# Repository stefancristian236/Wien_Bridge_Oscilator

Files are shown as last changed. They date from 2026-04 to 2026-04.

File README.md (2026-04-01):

# Wien Bridge Oscillator

## Schematic & PCB
Full schematic and simulation is available in the 'Wien_oscillator' file in LTSpice.
The PCB can be accessed using a proper PCB design software and accessing the 'oscilatorWien3.brd' file.
The circuit was simulated in LTSpice and routed in OrCAD.

## Documentation
Full project documentation (schematic, simulation results, design decisions) is available in 'DOC.pdf'.

## Gerber Files
Fabrication-ready files are in the `/Layout` folder.

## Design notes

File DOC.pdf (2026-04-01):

Anul universitar: 2025-2026

## UNIVESITATEA NAȚIONALĂ DE ȘTIINȚE ȘI TEHNOLOGIE POLITEHNICĂ BUCUREȘTI

FACULTATEA DE ELECTRONICĂ, TELECOMUNICAȚII ȘI

TEHNOLOGIA INFORMAȚIEI

## PROIECT 1 – CIRCUITE ELECTRONICE FUNDAMENTALE 2

## OSCILATOR CU PUNTE WIEN

Profesori Îndrumători:

S.I. Dr.Ing. Miron Cristea Dr.Ing. Niculina Draghici

Student:
Grecu Stefan-Cristian
Grupa 434C

## Cuprins

## 1. Tema Proiectului(N = 16)

### Se dorește proiectarea unui oscilator cu punte Wien având următoarele specificații:

- Frecvența de oscilație fixă, f = N [kHz] - Amplitudinea semnalului de la ieșire peak-to-peak de N/3 + 2 [V] - Sarcina la ieșire de 50N [Ω] - Rețeaua de reactive pozitivă din componenta oscilatorului să fie de tip Wien - Domeniul temperaturilor de funcționare 0 – 70 grade Celsius - Amplificarea în tensiune minimă a amplificatorului să fie minim 200 - Se folosesc componente discrete, fără circuite integrate

### Pentru N = 16, obținem următoarele specificații:

### - f = 16 [kHz] - App = 7.33 [V] - Sarcina R = 800 [Ω]

## 2. Schema Bloc

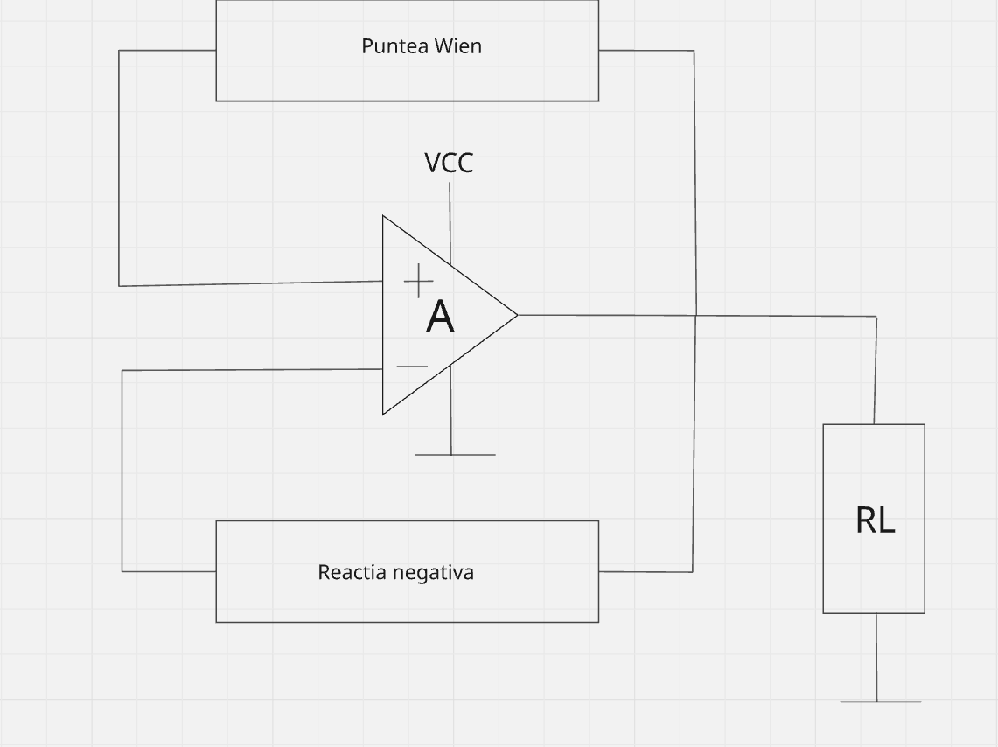
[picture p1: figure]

## 2.1 Blocul “Puntea Wien”

Reprezintă reacția pozitivă a amplificatorului operațional notat cu A. Acesta asigură, prin intermediul unei legături dublu π (deoarece există o legătură RC serie cu o legătură RC paralel), frecvența de oscilație de la ieșire. Reacția este fizic implementată cu ajutorul a 3 rezistențe și 2 condensatoare care, după formulaf0 =

1
2πRC

trebuie să rezulte N,

adică valoarea de 16 [kHz].

## 2.2 Blocul “Reactia Negativă”

Rolul principal al acestui bloc este de a modifica câștigul amplificatorului, astfel încât în buclă deschisă să fie cât mai mare, iar în buclă închisă acesta să fie exact 3 pentru a putea susține oscilațiile. Totodată, acest bloc se ocupă cu modificarea amplitudinii semnalului.

## 2.3 Blocul amplificator(A)

Acest bloc este inima circuitului; rolul acestuia este de a amplifica diferența de potențial de la intrările sale. În cazul lui, acesta trebuie să aibă o amplificare cât mai mare (de dorit, sau teoretic, această amplificare trebuie să fie chiar infinită).

## 2.4 Blocul RL(sarcina)

Acesta are rolul de consumator în circuitul nostru; astfel, acesta este conectat la ieșirea opamp-ului și pe el pică semnalul generat de circuit.

## 3.Implementarea Blocurilor

Ulterior, după ce am implementat în LTSpice schema bloc din capitolul anterior, am ajuns la circuitul funcțional de mai jos, urmând ca în cele ce urmează să trecem prin fiecare bloc în parte.

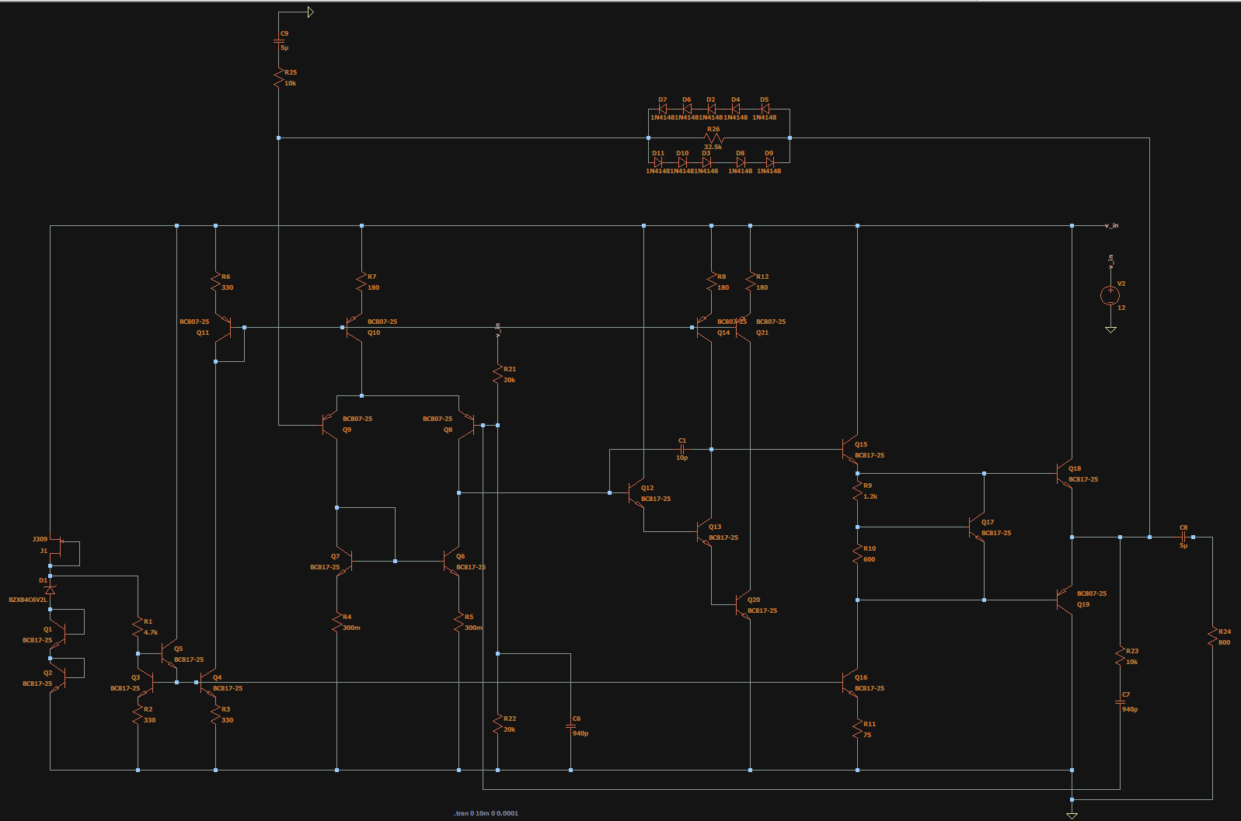
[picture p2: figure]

## 3.1 Blocul “Puntea Wien”

Așa cum am specificat în capitolul anterior, rolul punții Wien este de a genera oscilații, fiind formată dintr-o rețea RC serie și o rețea RC paralel, numită și „dublu π”.

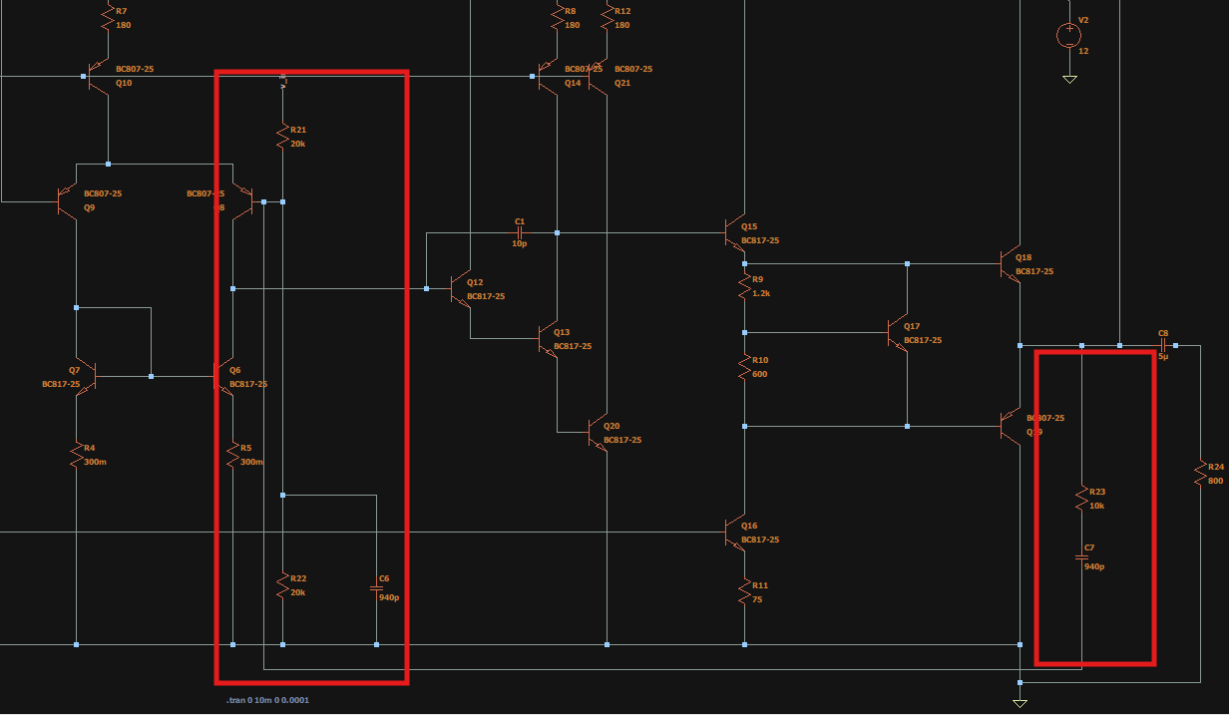
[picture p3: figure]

Rețeaua este construită din 2 rezistențe R21 și R22 de 20k legate în paralel, astfel rezistența echivalentă a acestora va fi 10k. În cazul condensatoarelor am utilizat capacitate de 940 [pF]; chiar dacă în urma calculelor ajungem la o frecvență mai mare de 16k, în practică, din cauza că circuitul introduce o formă de phase lag, frecvența este apropiată de 16 [kHz]. În cele ce urmează efectuăm calculul pentru frecvența necesară.Frecvența se calculează cu formula:f0 =

1
2πRC

Știm că f0 = 16[Kℎz] => RC =

1
2πf0

=> RC =

1
2π⋅16

și dacă rezolvăm pentru una din

componente : R =

1
2π⋅16C

, și pentru valoarea C = 900[pF] obținem o rezistență

R ≈ 11[kΩ] dar din cauza fenomenului de phase lag am ales valorile

R = 10[kΩ] si C = 940[pF], care ne oferă o valoare apropiată de frecvența țintă, 16 [kHz].

## 3.2 Blocul „Reacție Negativă”

Reacția negativă are loc pentru a modifica câștigul amplificării, să menținem amplificarea la valoarea de 3, în cazul nostru, inclusiv să compensăm scăderea acesteia cu ajutorul unor perechi de diode în antiparalel și, nu în ultimul rând, să obținem amplitudinea țintă.

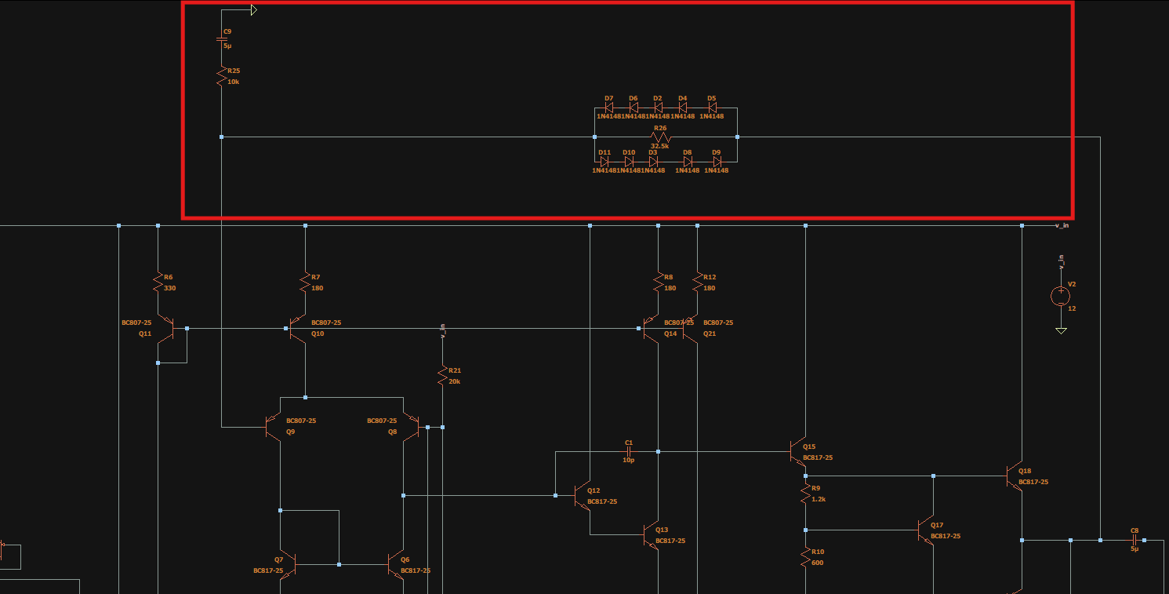
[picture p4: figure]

Reacția negativă este formată din rezistențele R26, R25, condensatorul C9 și cele 10 diode, menite să mențină amplificarea stabilă (sau, mai corect, să o compenseze) și să întrețină oscilațiile.
În cazul unui oscillator cu punte Wien, amplificarea în buclă închisă trebuie să fie exact 3; ținând cont că avem un amplificator neinversor, putem scrie că

vout = (1 +

Rf
Ri) Vin ⇒

vout

vin

= 1 +

Rf
Ri

⇒ A = 1 +

R26
R25

, cum A = 3 ⇒

R26
R25

= 2, deci obținem

condiția de oscilație: R26 = 2R25, dar acest lucru este teoretic, deoarece în practică amplificatorul ar avea nevoie de mai mult pentru a începe oscilațiile, motiv pentru care în cazul nostru R26este de aproximativ 3 ori R25.
Diodele au rolul de a ajuta la menținerea amplitudinii oscilațiilor, dar și pentru compensarea amplificării; astfel se asigură amplitudinea și oscilațiile necesare.

## 3.3 Blocul Amplificator (A)

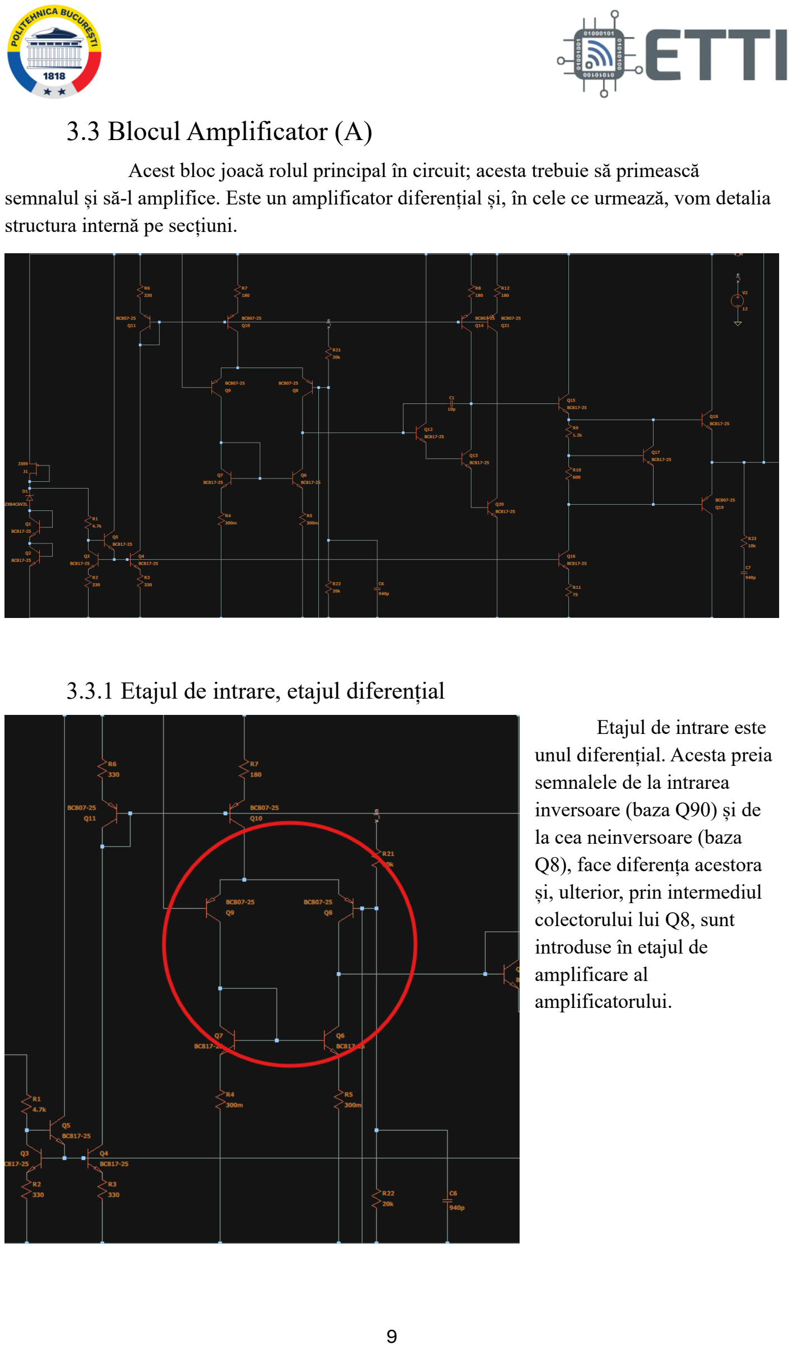
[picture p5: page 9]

Acest bloc joacă rolul principal în circuit; acesta trebuie să primească semnalul și să-l amplifice. Este un amplificator diferențial și, în cele ce urmează, vom detalia structura internă pe secțiuni.

### 3.3.1 Etajul de intrare, etajul diferențial

Etajul de intrare este
unul diferențial. Acesta preia semnalele de la intrarea
inversoare (baza Q90) și de la cea neinversoare (baza
Q8), face diferența acestora și, ulterior, prin intermediul colectorului lui Q8, sunt
introduse în etajul de
amplificare al
amplificatorului.

### 3.3.2 Etajul de amplificare

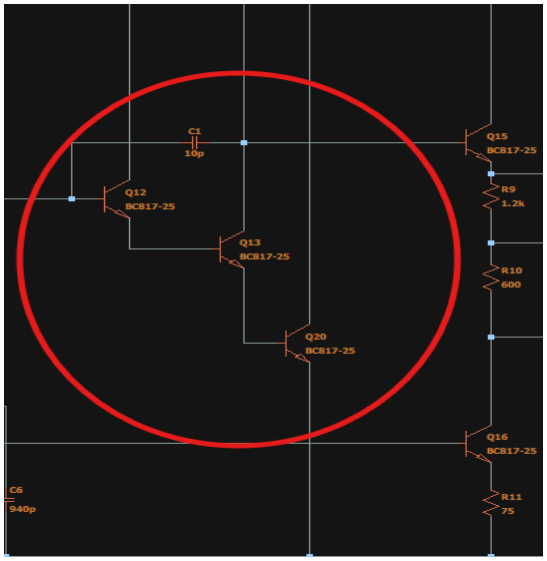
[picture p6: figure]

Etajul de amplificare este confecționat din 3 tranzistoare bipolare montate în cascadă și un condensator de compensare Miller.

Condensatorul are un rol important în menținerea stabilității circuitului. Totodată, acesta profită de efectul Miller, Cechivalent = C(1+Av

), unde Aveste câștigul etajului care se află în conexiune Darlington. Prin acest efect, condensatorul, văzut dinspre bază, are o capacitate mai mare, factor important pentru filtrarea semnalului și care ajută la menținerea unor oscilații stabile.

### 3.3.3 Etajul de ieșire

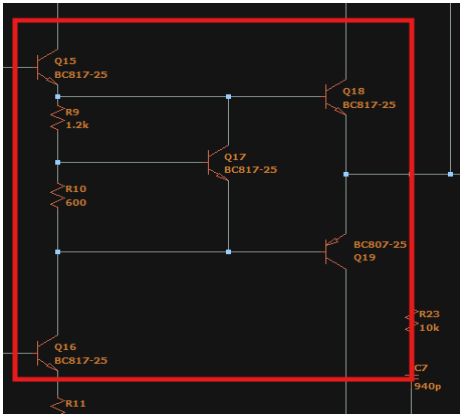
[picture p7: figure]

Ieșirea amplificatorului este de clasă AB. Tranzistorul Q17 are rolul de a menține un curent de repaus în bazele tranzistorilor Q18 și Q19, motiv pentru care ei rămân ușor sau aproape deschiși chiar și dacă nu ajunge semnal la ei. Aceasta asigură eliminarea distorsiunilor și o ieșire mai liniară.

### 3.3.4 Sursa de current si oglinzile de current

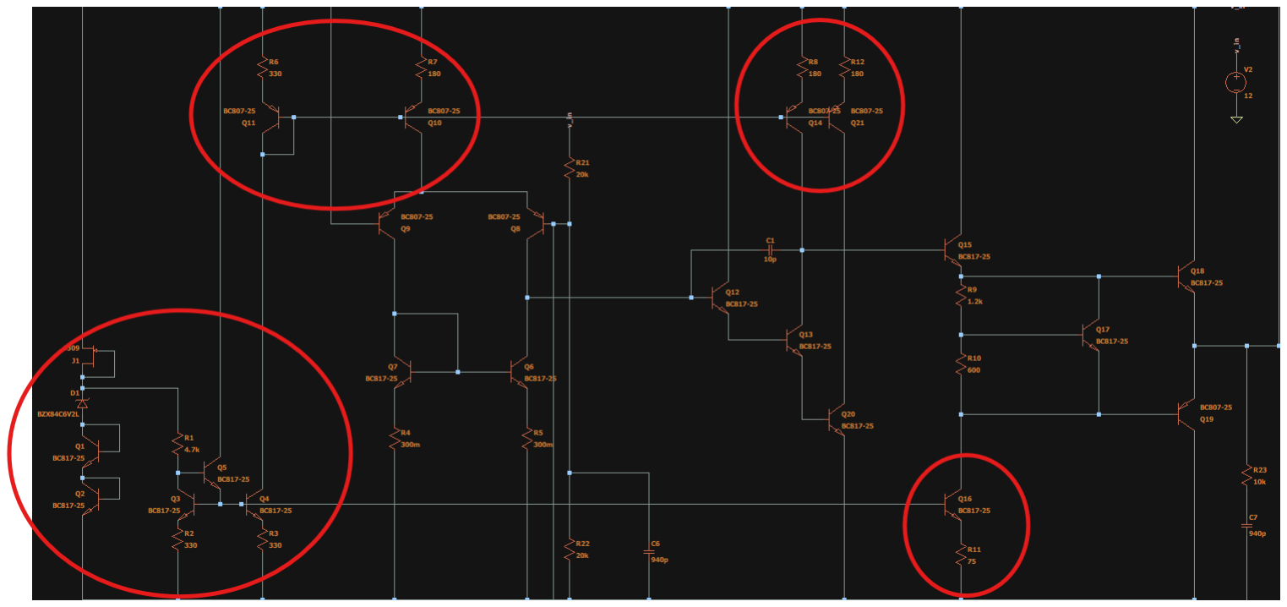
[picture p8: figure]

Sursa de curent asigură polarizarea corectă a tranzistoarelor; utilizarea unei surse oferă un curent constant, lucru care nu ar fi fost posibil dacă foloseam rezistențe simple, deoarece curentul ar fluctua odată cu variațiile sursei de alimentare.

În primul rând avem JET-ul (J1) și dioda Zener (stânga jos), care creează o tensiune de referință foarte stabilă și curată. Întregul ansamblu formează un generator de curent constant.

Avem apoi oglinzile de curent, care se află atât în partea superioară, cât și în partea inferioară; acestea oglindesc curentul pe care îl stabilim în generatorul de curent, astfel acesta poate fi purtat prin toți tranzistorii și asigură o polarizare corectă, independentă de fluctuațiile sursei de alimentare.

## 4. Simulari

Pentru simulare circuitului am utilizat programul: LTSpice.

## 4.1 Vizionarea functionarii circuitului, analiza in timp AC

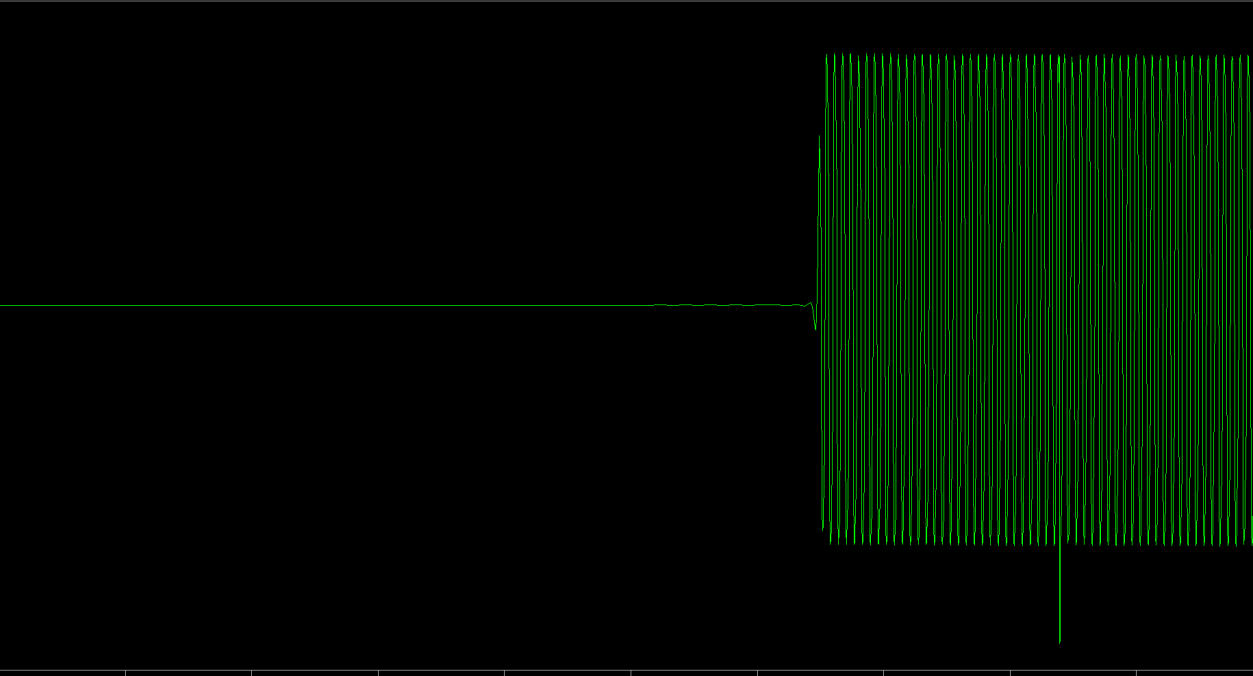
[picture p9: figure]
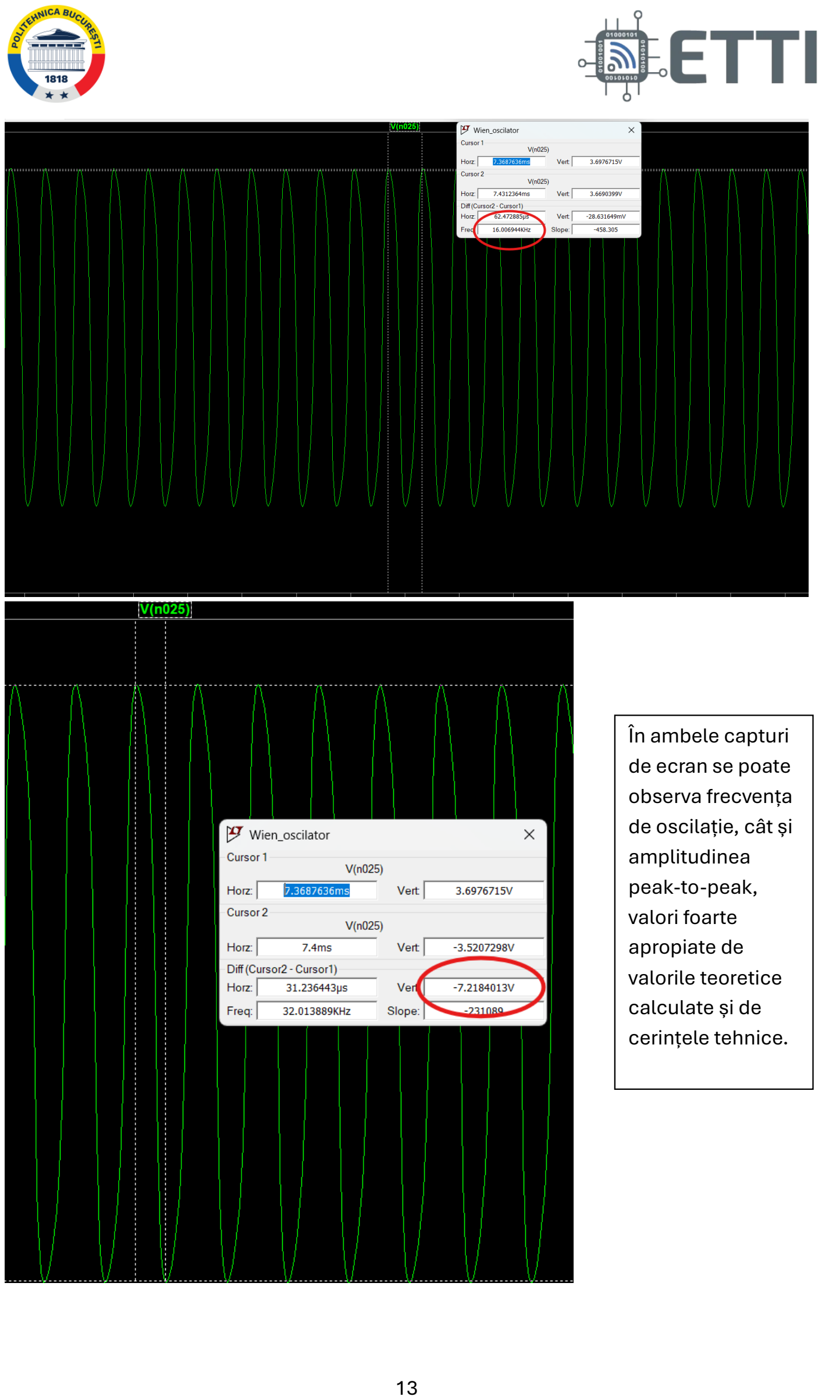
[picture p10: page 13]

## În ambele capturi de ecran se poate observa frecvența de oscilație, cât și amplitudinea

peak-to-peak,

## valori foarte apropiate de valorile teoretice calculate și de

cerințele tehnice.

## 4.2 Amplificarea in bucla deschisa(open loop gain)

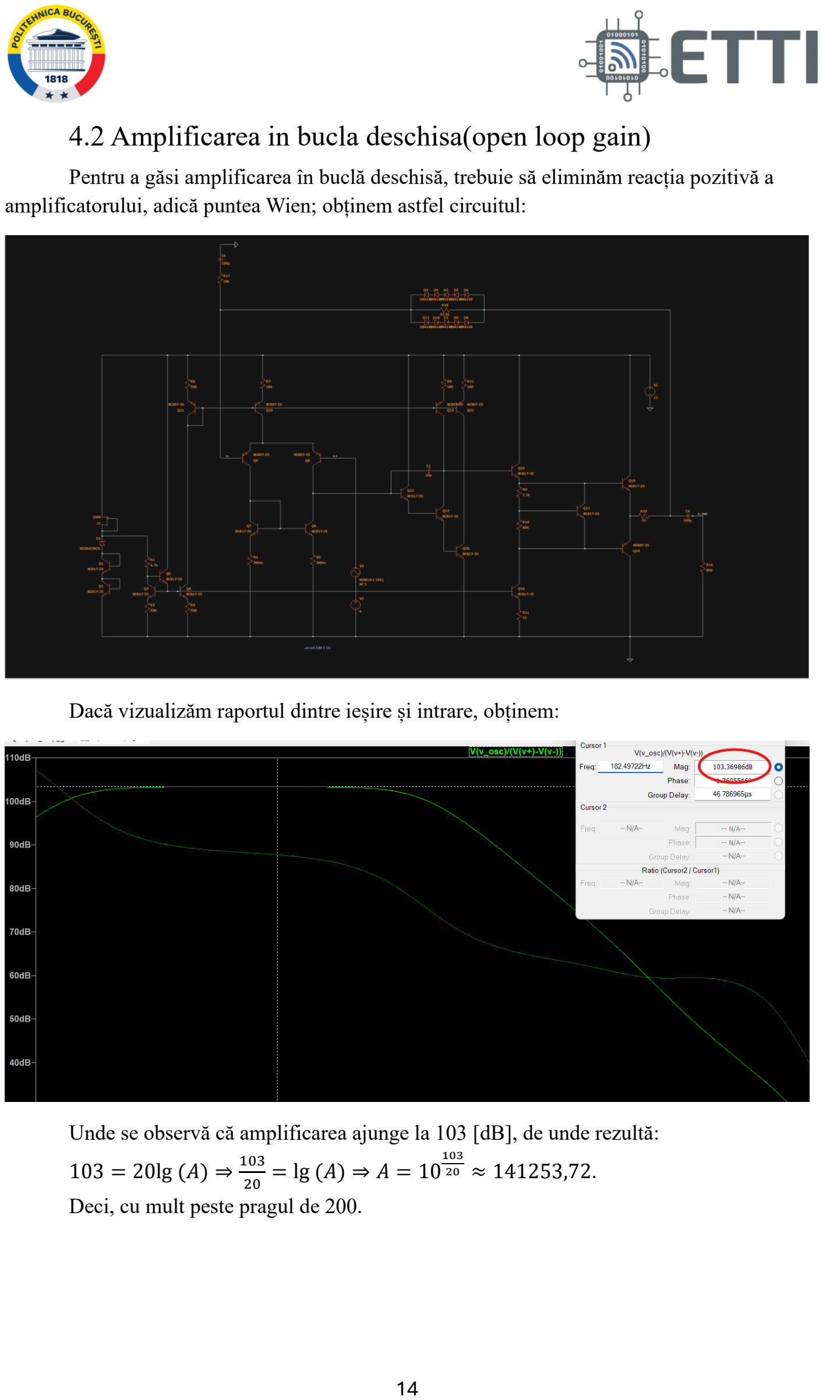
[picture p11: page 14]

Pentru a găsi amplificarea în buclă deschisă, trebuie să eliminăm reacția pozitivă a amplificatorului, adică puntea Wien; obținem astfel circuitul:

Dacă vizualizăm raportul dintre ieșire și intrare, obținem:

Unde se observă că amplificarea ajunge la 103 [dB], de unde rezultă: 103 = 20lg (A) ⇒

103
20

= lg (A) ⇒ A = 10

103
20 ≈ 141253,72.

Deci, cu mult peste pragul de 200.

## 4.3 Variatia cu temperatura a circuitului

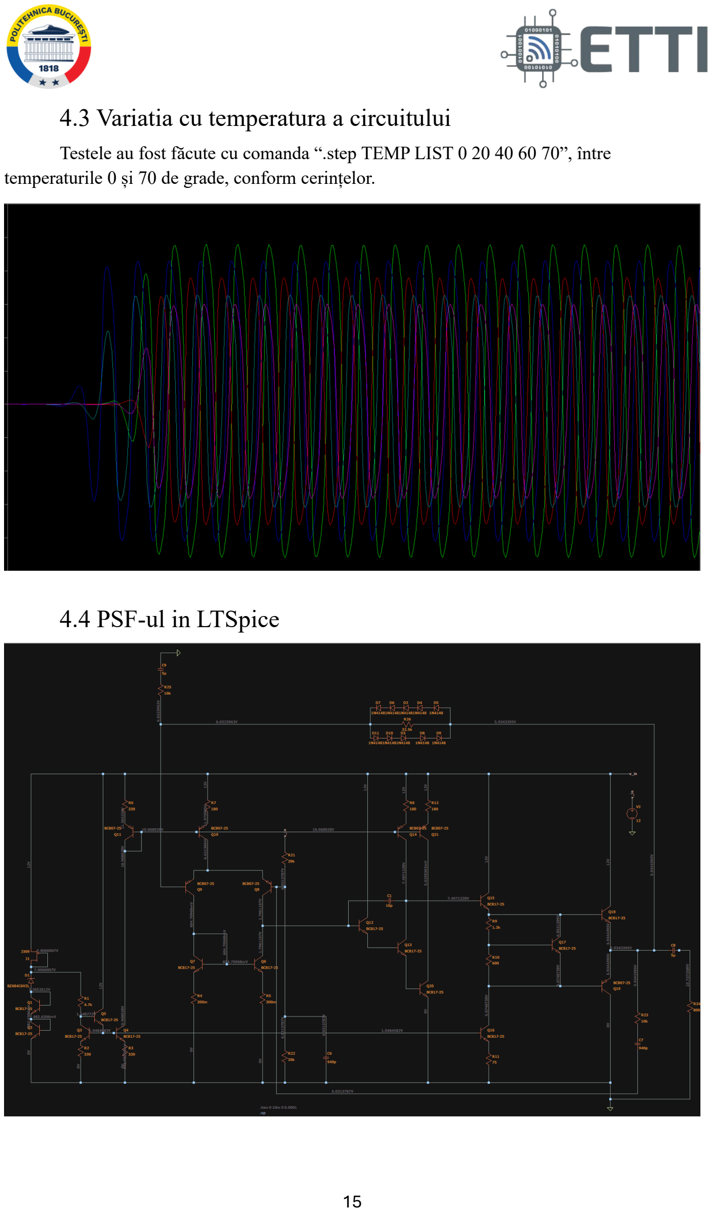
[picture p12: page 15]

Testele au fost făcute cu comanda “.step TEMP LIST 0 20 40 60 70”, între temperaturile 0 și 70 de grade, conform cerințelor.

## 4.4 PSF-ul in LTSpice

## 4.5 PSF de mana

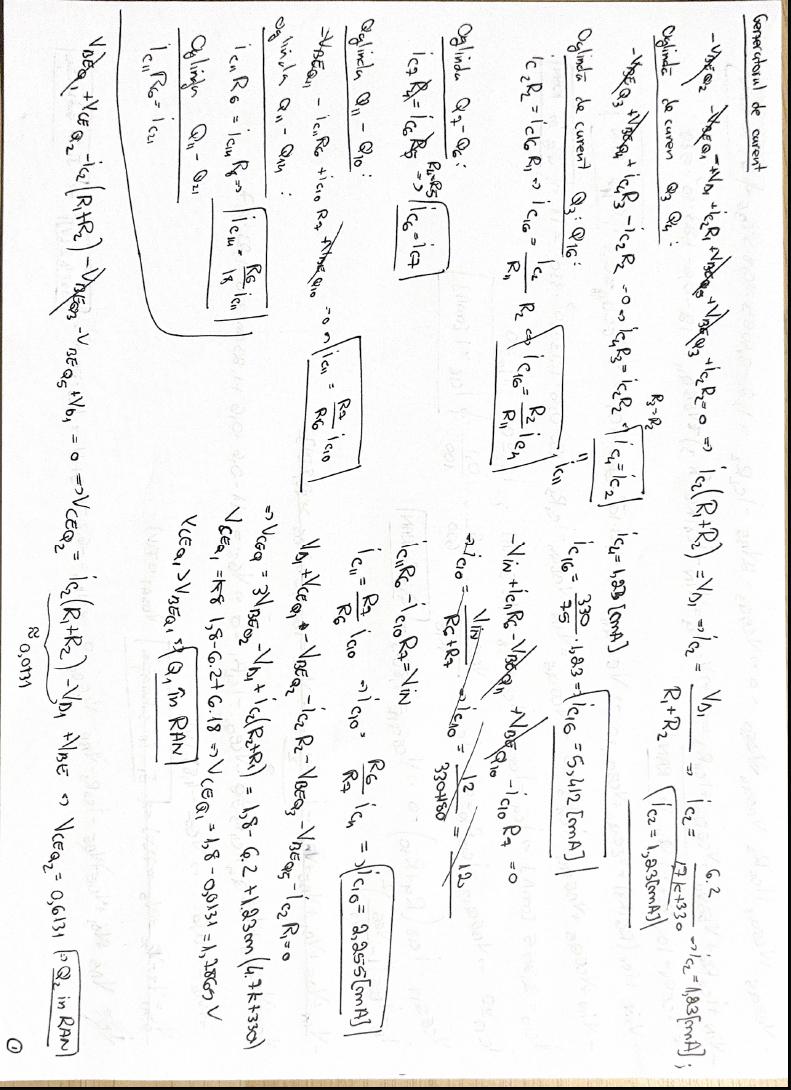
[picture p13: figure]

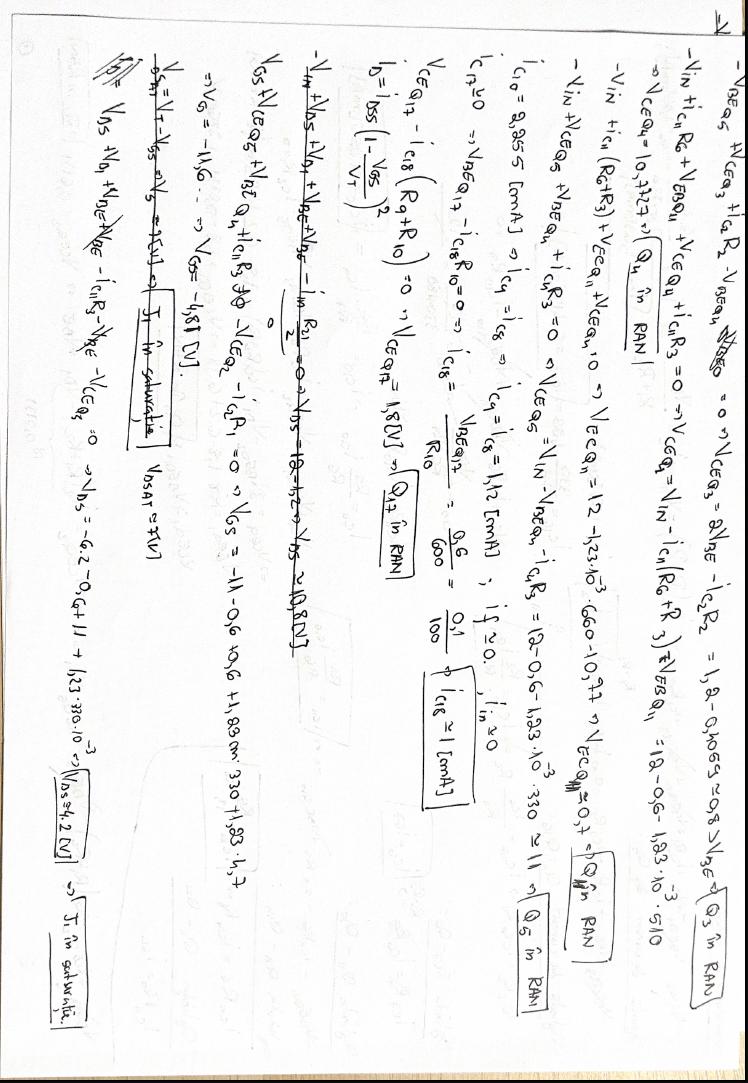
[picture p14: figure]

## 5.BOM

Nr. Crt. | Nume | Catalog | Cod distrib | Nume prod | Prod | Clasă | Qty fix | Qty final | Qty min | Descriere | Distribuitor | Pret (fara TVA) referinta/bu c. TME România | Pret total pe reper (fara TVA) -propus
7 | 33 | (LINK) | SMD0805-33R-5% | 0805S8J033 0T5E | ROYAL OHM | rezistor | | | 3 | Rezistor SMD, chip, 0805, 33Ω, ±5%, 0.125W | TME România | | 0
10 | 82 | (LINK) | SMD0805-82R-5% | WF08P820J TL | WALSIN | rezistor | | | 1 | Rezistor SMD, chip, 0805, 82Ω, ±5%, 0.125W | TME România | | 0
12 | 150 | (LINK) | SMD0805-150R-5% | 0805S8F150 0T5E | ROYAL OHM | rezistor | | | 2 | Rezistor SMD, chip, 0805, 150Ω, ±5%, 0.125W | TME România | | 0
15 | 470 | (LINK) | SMD0805-470R-5% | 0805S8J047 1T5E | ROYAL OHM | rezistor | | | 2 | Rezistor SMD, chip, 0805, 470Ω, ±5%, 0.125W | TME România | | 0
17 | 680 | (LINK) | SMD0805-680R-5% | 0805S8J068 1T5E | ROYAL OHM | rezistor | | | 1 | Rezistor SMD, chip, 0805, 680Ω, ±5%, 0.125W | TME România | | 0
18 | 820 | (LINK) | SMD0805-820R-5% | 0805S8J082 1T5E | ROYAL OHM | rezistor | | | 1 | Rezistor SMD, chip, 0805, 820Ω, ±5%, 0.125W | TME România | | 0
21 | 1.5k | (LINK) | SMD0805-1K5-5% | WF08P152J TL | WALSIN | rezistor | | | 1 | Rezistor SMD, chip, 0805, 1.5kΩ, ±5%, 0.125W | TME România | | 0
28 | 4.7k | (LINK) | SMD0805-4K7-5% | 0805S8J047 2T5E | ROYAL OHM | rezistor | | | 1 | Rezistor SMD, chip, 0805, 4.7kΩ, ±5%, 0.125W | TME România | | 0
33 | 10k | (LINK) | SMD0805-10K-5% | 0805S8J010 3T5E | ROYAL OHM | rezistor | | | 3 | Rezistor SMD, chip, 0805, 10kΩ, ±5%, 0.125W | TME România | | 0
35 | 22k | (LINK) | SMD0805-22K-5% | 0805S8J022 3T5E | ROYAL OHM | rezistor | | | 3 | Rezistor SMD, chip, 0805, 22kΩ, ±5%, 0.125W | TME România | | 0
58 | 10pF | (LINK) | CC0805JRN PO9BN100 | CC0805JRN PO9BN100 | YAGEO | condensator | | | 1 | ceramic; MLCC; 10pF; 50V; C0G; ±5%; SMD; 0805 | TME România | | 0
62 | 1nF | (LINK) | CL21C102JB CNNNC | CL21C102JB CNNNC | SAMSUNG | condensator | | | 2 | Condensator MLCC, SMD, 0805, 1nF, ±5%, 50V, C0G | TME România | | 0
75 | 4.7uF | (LINK) | CL21A475K AQNNNG | CL21A475K AQNNNG | SAMSUNG | condensator | | | 2 | ceramic; MLCC; 4,7uF; 25V; X5R; ±10%; SMD; 0805 | TME România | | 0
77 | 4148 | (LINK) | 1N4148-0805 | CD4148WS( 0805C) | DC Components | diodă pn | | | 2 | Diodă comutație, SMD, 0805, 300mA, 100V | TME România | | 0
84 | 8.2V | (LINK) | BZX84C8V2 | BZX84-C8V2 | NEXPERIA | diodă Zener | | | 1 | Diodă Zener, SMD, SOT23, 8.2V, ±5%, 0.3W | TME România | | 0
89 | N-JFET | (LINK) | MMBFJ309L T1G | MMBFJ309L T1G | ON Semiconduc tor | tranzistor NJFET | | | 1 | Tranzistor N-JFET, SMD, SOT23, 25V, 30mA | TME România | | 0
91 | NPN | (LINK) | BC817-25-DIO | BC817-25-DIO | NXP | tranzistor bipolar | | | 14 | Tranzistor bipolar NPN, SMD, SOT23, 45V, 800mA | TME România | | 0
93 | PNP | (LINK) | BC807-25-DIO | BC807-25-DIO | NXP | tranzistor bipolar | | | 5 | Tranzistor bipolar PNP, SMD, SOT23, 45V, 800mA | TME România | | 0
98 | Conn2p | (LINK) | ZL301-40P | ZL301-40P | NINIGI | Sir pini, pas 2,54mm, SMD | 0 2 | | | Sir pini, pas 2,54mm, SMD, tip tata, bareta de 40 pini | TME România | | 0

## 6.Bibliografie

- Curs CIA
- Curs CEF
- https://www.geeksforgeeks.org/electrical-engineering/wien-bridge-oscillator/

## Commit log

2026-04-01 Added the base files
    [oscilatorWien3.brd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]
2026-04-01 added the .brd to be opened in OrCAD
    [oscilatorWien3.brd]
